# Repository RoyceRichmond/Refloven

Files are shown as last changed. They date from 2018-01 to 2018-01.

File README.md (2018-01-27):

# Refloven

this projects aims to be a low cost and customisable reflow oven board, i inspired this in the job made by @rocketscream reflow oven shield with some additional hardware so it can have more I/O pins avaliable and also usb so there's need of external programmer.

currently working to fix some problems, v2 is actually really stable and works fine. have fun and as a side note, use the v1 to make the v2 got it ? (like a 3d printer )

v1 is the easies one to build, all by hand and some extra wire.

v2 is a little more complicated to, but if you sucessfully assembled v1 and tested it you have everything on your side. it works either with 328p or 328pb only difference is how to program it and the mapping of the i/o

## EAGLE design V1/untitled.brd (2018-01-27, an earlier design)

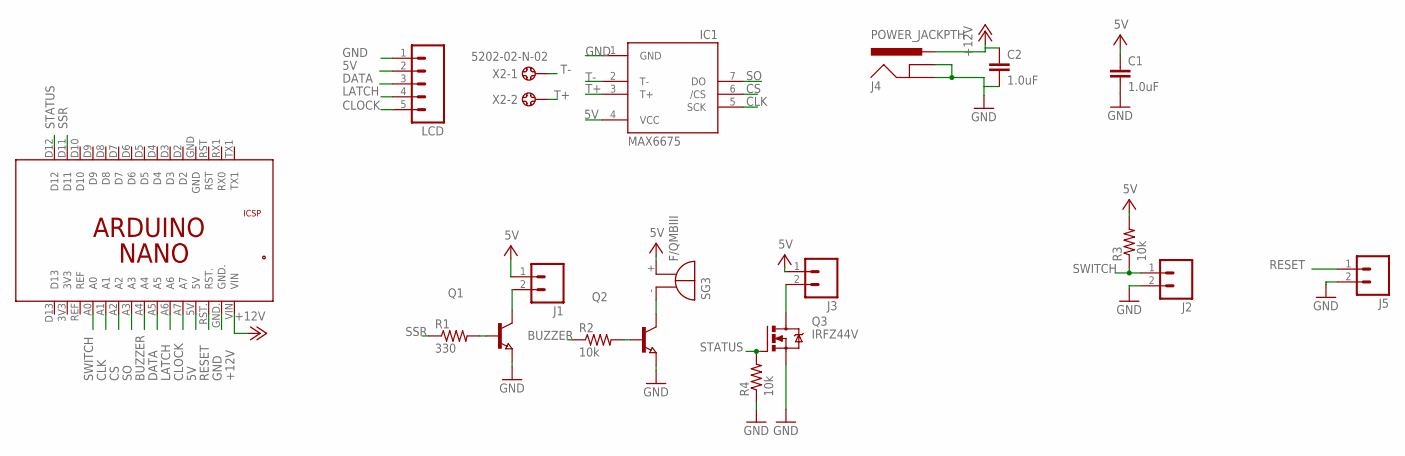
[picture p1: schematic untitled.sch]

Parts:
C1, C2: 1.0uF; 1206-CAP
IC1: MAX6675; SO08
J1, J2, J3, J5: M02PTH; 1X02
J4: POWER_JACKPTH; POWER_JACK_PTH
LCD: M05PTH; 1X05
PCB2: ARDUINO_NANO_RHEYD; ARDUINO_NANO
Q1, Q2: NPN-TRANSISTOR_SOT23; SOT23
Q3: IRFZ44V; TO220BH
R1: 330; R1206
R2, R3, R4: 10k; R1206
SG3: F/QMBIII
X2: 5202-02-N-02

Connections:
5V: C1.1, IC1.4 (VCC), J1.1, J3.1, LCD.2, PCB2.5V, R3.2, SG3.+ (-)
+12V: C2.1, J4.PWR, PCB2.VIN
BUZZER: PCB2.A4, R2.1
CLK: IC1.5 (SCK), PCB2.A1
CLOCK: LCD.5, PCB2.A7
CS: IC1.6 (/CS), PCB2.A2
DATA: LCD.3, PCB2.A5
GND: C1.2, C2.2, IC1.1 (GND), J2.2, J4.GND, J4.GNDBREAK, J5.2, LCD.1, PCB2.GND., Q1.2 (E), Q2.2 (E), Q3.S, R4.1
LATCH: LCD.4, PCB2.A6
unnamed: Q1.1 (B), R1.2
unnamed: Q2.1 (B), R2.2
unnamed: Q2.3 (C), SG3.- (+)
unnamed: J1.2, Q1.3 (C)
unnamed: J3.2, Q3.D
RESET: J5.1, PCB2.RST.
SO: IC1.7 (DO), PCB2.A3
SSR: PCB2.D11, R1.1
STATUS: PCB2.D12, Q3.G, R4.2
SWITCH: J2.1, PCB2.A0, R3.1
T+: IC1.3 (T+), X2.2
T-: IC1.2 (T-), X2.1

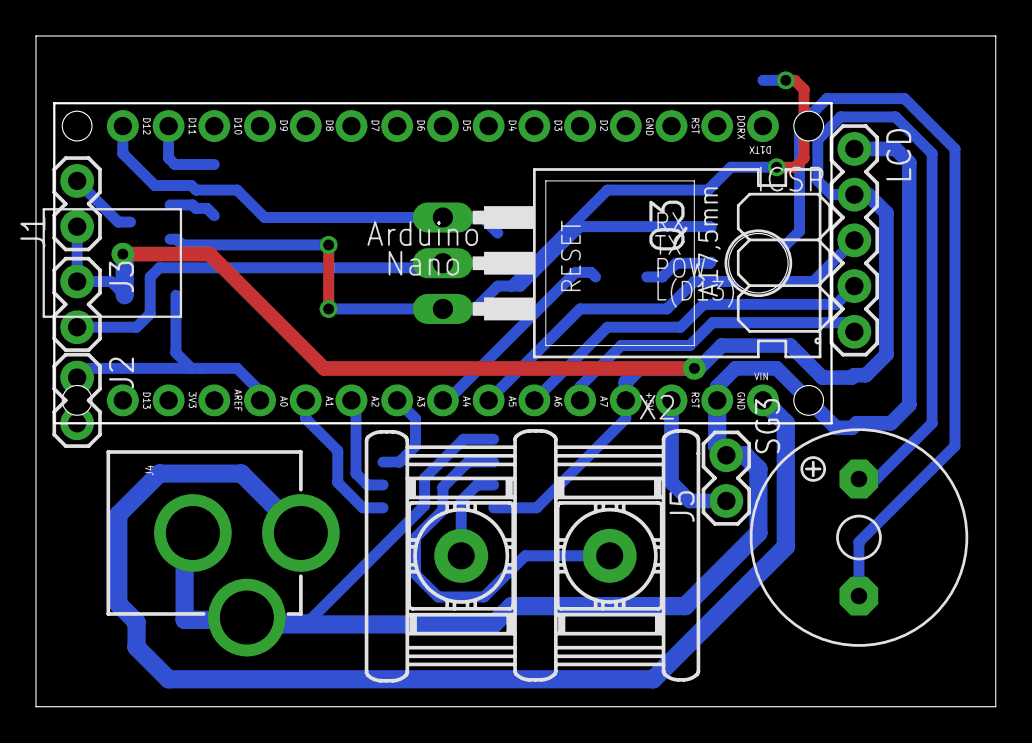
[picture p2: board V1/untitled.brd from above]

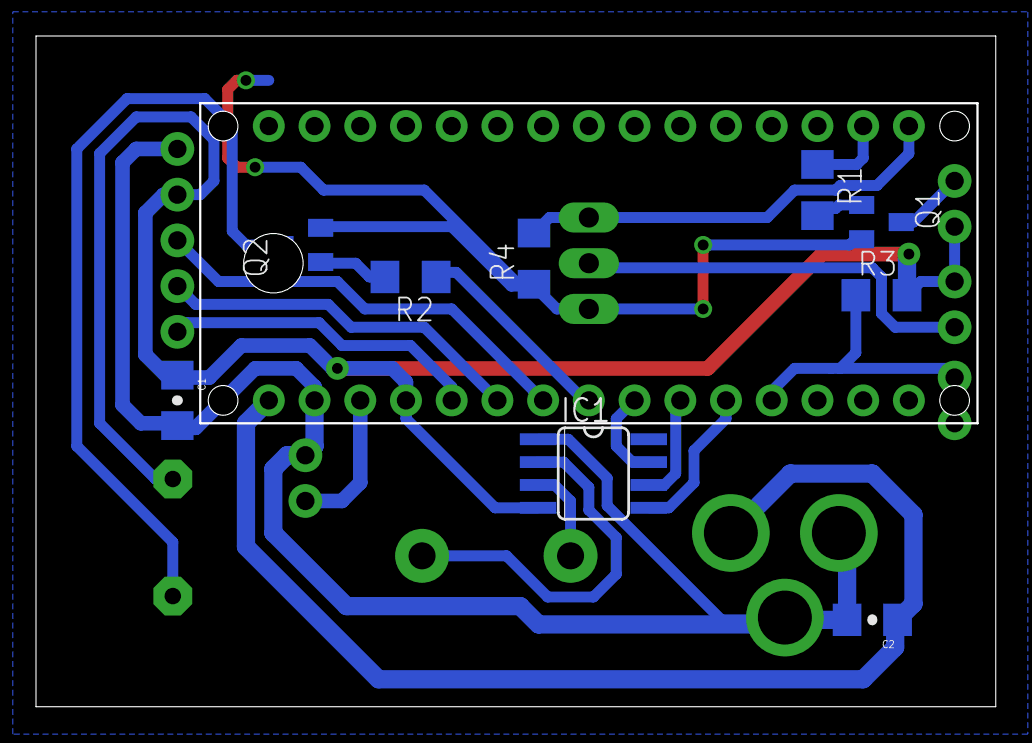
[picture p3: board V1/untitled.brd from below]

Board: 2 copper layers, 53.3 x 37.3 mm, 19 parts (9 on the bottom side), 21 nets.

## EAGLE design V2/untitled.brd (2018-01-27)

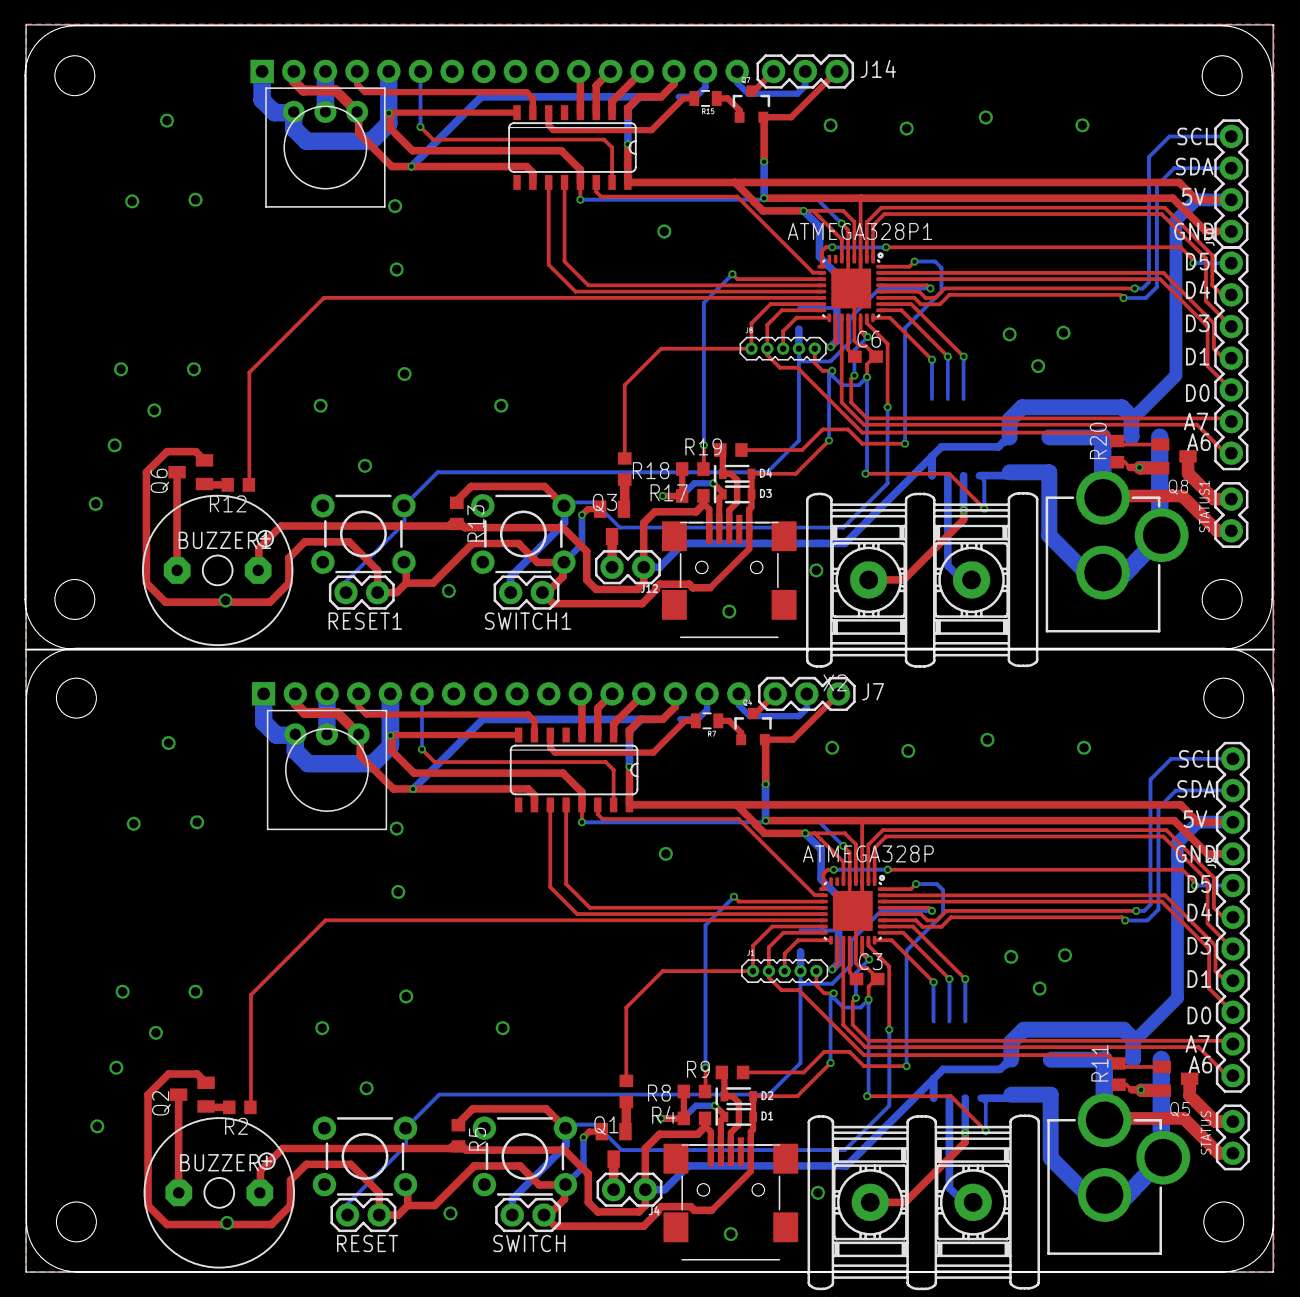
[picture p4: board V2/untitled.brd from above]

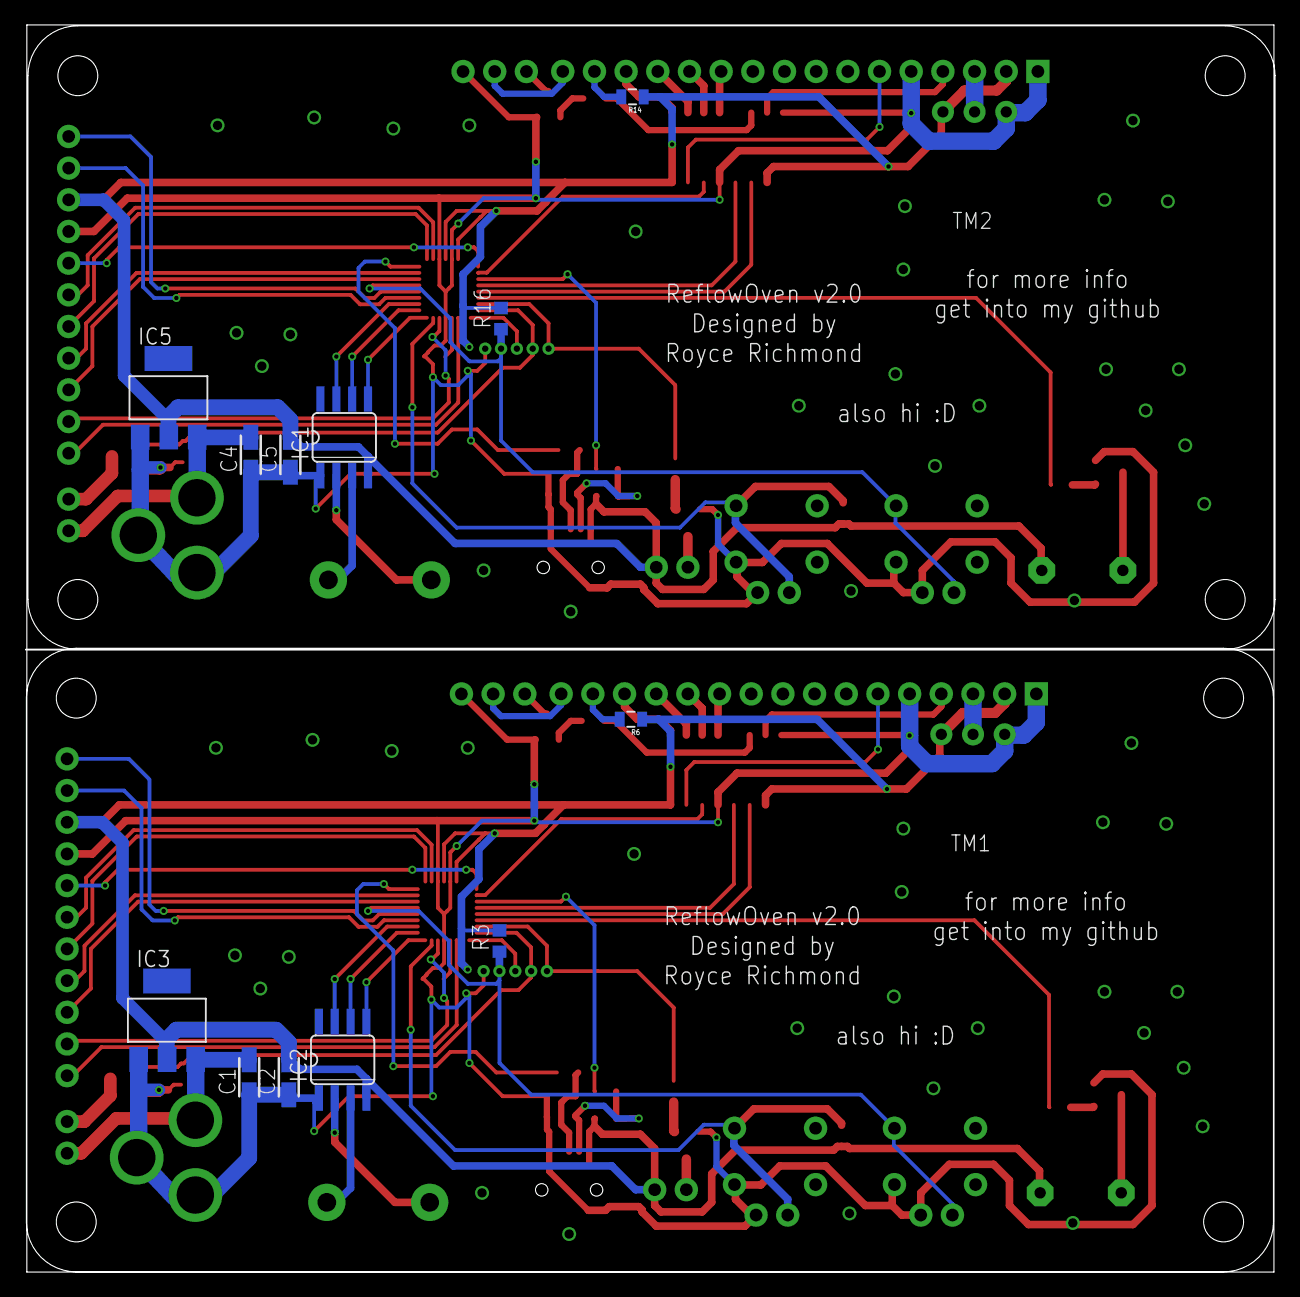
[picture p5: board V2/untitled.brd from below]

Board: 2 copper layers, 100.0 x 100.0 mm, 80 parts (12 on the bottom side), 95 nets.

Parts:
ATMEGA328P, ATMEGA328P1: MLF32-PAD
BUZZER, BUZZER1: F/QMBIII
C1, C2, C4, C5: 10uF; CT3216
C3, C6: C0603
CN1, CN2: USB-MINIB
D1, D2, D3, D4: 3.6V; SOD-323
IC1, IC2: MAX6675; SO08
IC3, IC5: REG1117; SOT223
IC4, IC6: 74LS595D; SO16
J1, J8: 1X05-1.27MM
J2, J10: 1X04
J3, J11: POWER_JACK; POWER_JACK_PTH
J4, J5, J6, J12, J13, J15: 1X02
J7, J14: 1X03
J9, J16: 1X07
PCB1, PCB2: PCB_DP_RECTANGLE-50X100; DP10050_V1
Q1, Q2, Q3, Q5, Q6, Q8: SOT23
Q4, Q7: MMBT2222A; SOT23-3
R1, R2, R10, R12: 330; R0603
R3, R5, R11, R13, R16, R20: 10k; R0603
R4, R17: 1.5K; R0603
R6, R14: 330; 0805
R7, R15: 1K; 0805
R8, R9, R18, R19: 68; R0603
RESET, RESET1: MOMENTARY-SWITCH-SPST-PTH-6.0MM; TACTILE_SWITCH_PTH_6.0MM
STATUS, STATUS1: 1X02
SWITCH, SWITCH1: MOMENTARY-SWITCH-SPST-PTH-6.0MM; TACTILE_SWITCH_PTH_6.0MM
TM1, TM2: TRIM-3386
U1, U3: LCD-16X2NOHOLES; LCD-16X2_NOHOLES
X1, X2: 5202-02-N-02

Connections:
+5V: ATMEGA328P.4, ATMEGA328P.6, ATMEGA328P.18, BUZZER.+, C2.+, CN1.VBUS, IC2.4, IC3.2, IC4.10, IC4.16, J2.2, J4.1, R3.2, R4.2, R5.2, R6.1, TM1.1, U3.2
+5V1: ATMEGA328P1.4, ATMEGA328P1.6, ATMEGA328P1.18, BUZZER1.+, C5.+, CN2.VBUS, IC1.4, IC5.2, IC6.10, IC6.16, J10.2, J12.1, R13.2, R14.1, R16.2, R17.2, TM2.1, U1.2
+12V: C1.+, IC3.3, J3.PWR, STATUS.1
+12V1: C4.+, IC5.3, J11.PWR, STATUS1.1
A1: ATMEGA328P1.19, J16.1
A2: ATMEGA328P1.22, J16.2
A6: ATMEGA328P.19, J9.1
A7: ATMEGA328P.22, J9.2
BUZZER: ATMEGA328P.14, R2.1
BUZZER1: ATMEGA328P1.14, R12.1
CLK: ATMEGA328P.24, IC2.5
CLK1: ATMEGA328P1.24, IC1.5
CLOCK: ATMEGA328P.13, IC4.11
CLOCK1: ATMEGA328P1.13, IC6.11
CS: ATMEGA328P.25, IC2.6
CS1: ATMEGA328P1.25, IC1.6
D1: ATMEGA328P1.17, J8.3
D2: ATMEGA328P.32, R9.1
D3: ATMEGA328P.1, J9.5
D4: ATMEGA328P.2, J9.6
D5: ATMEGA328P.9, J9.7
D6: ATMEGA328P1.11, R18.1
D7: ATMEGA328P.11, R8.1
D8: ATMEGA328P1.9, J16.7
D9: ATMEGA328P1.2, J16.6
D10: ATMEGA328P1.1, J16.5
D11: ATMEGA328P1.32, R19.1
D13: ATMEGA328P.17, J1.3
DATA: ATMEGA328P.10, IC4.14
DATA1: ATMEGA328P1.10, IC6.14
GND: ATMEGA328P.3, ATMEGA328P.5, ATMEGA328P.21, ATMEGA328P.PAD, ATMEGA328P1.3, ATMEGA328P1.5, ATMEGA328P1.21, ATMEGA328P1.PAD, C1.-, C2.-, C3.2, C4.-, C5.-, C6.2, CN1.GND, CN2.GND, D1.A, D2.A, D3.A, D4.A, IC1.1, IC2.1, IC3.1, IC4.8, IC4.13, IC5.1, IC6.8, IC6.13, J1.5, J2.1, J3.GND, J3.GNDBREAK, J5.2, J6.2, J7.1, J8.5, J10.1, J11.GND, J11.GNDBREAK, J13.2, J14.1, J15.2, Q1.2, Q2.2, Q3.2, Q4.2, Q5.2, Q6.2, Q7.2, Q8.2, R11.1, R20.1, RESET.1, RESET1.1, SWITCH.1, SWITCH1.1, TM1.3, TM2.3, U1.1, U1.5, U3.1, U3.5
LATCH: ATMEGA328P.12, IC4.12
LATCH1: ATMEGA328P1.12, IC6.12
unnamed: BUZZER.-, Q2.3
unnamed: IC2.2, X1.1
unnamed: IC2.3, X1.2
unnamed: Q1.1, R1.2
unnamed: Q2.1, R2.2
unnamed: ATMEGA328P.20, C3.1
unnamed: J4.2, Q1.3
unnamed: R6.2, U3.15
unnamed: TM1.2, U3.3
unnamed: IC4.7, U3.4
unnamed: IC4.15, U3.6
unnamed: IC4.4, U3.11
unnamed: IC4.3, U3.12
unnamed: IC4.2, U3.13
unnamed: IC4.1, U3.14
unnamed: J7.2, U3.16
unnamed: J7.3, Q4.3
unnamed: Q4.1, R7.1
unnamed: IC4.6, R7.2
unnamed: CN1.D-, D1.C, R4.1, R8.2
unnamed: CN1.D+, D2.C, R9.2
unnamed: BUZZER1.-, Q6.3
unnamed: IC1.2, X2.1
unnamed: Q5.3, STATUS.2
unnamed: IC1.3, X2.2
unnamed: Q3.1, R10.2
unnamed: Q6.1, R12.2
unnamed: J12.2, Q3.3
unnamed: R14.2, U1.15
unnamed: TM2.2, U1.3
unnamed: IC6.7, U1.4
unnamed: IC6.15, U1.6
unnamed: IC6.4, U1.11
unnamed: IC6.3, U1.12
unnamed: IC6.2, U1.13
unnamed: IC6.1, U1.14
unnamed: J14.2, U1.16
unnamed: J14.3, Q7.3
unnamed: Q7.1, R15.1
unnamed: IC6.6, R15.2
unnamed: ATMEGA328P1.20, C6.1
unnamed: CN2.D-, D3.C, R17.1, R18.2
unnamed: CN2.D+, D4.C, R19.2
unnamed: Q8.3, STATUS1.2
RESET: ATMEGA328P.29, J1.4, J5.1, R3.1, RESET.3
RESET1: ATMEGA328P1.29, J8.4, J15.1, R16.1, RESET1.3
RXD: ATMEGA328P.30, J9.3
RXD1: ATMEGA328P1.30, J16.3
SCL: ATMEGA328P.28, J2.4
SCL1: ATMEGA328P1.28, J10.4
SDA: ATMEGA328P.27, J2.3
SDA1: ATMEGA328P1.27, J10.3
SO: ATMEGA328P.26, IC2.7
SO1: ATMEGA328P1.26, IC1.7
SSR: ATMEGA328P.15, J1.1, R1.1
SSR1: ATMEGA328P1.15, J8.1, R10.1
STATUS: ATMEGA328P.16, J1.2, Q5.1, R11.2
STATUS1: ATMEGA328P1.16, J8.2, Q8.1, R20.2
SWITCH: ATMEGA328P.23, J6.1, R5.1, SWITCH.3
SWITCH1: ATMEGA328P1.23, J13.1, R13.1, SWITCH1.3
TXD: ATMEGA328P.31, J9.4
TXD1: ATMEGA328P1.31, J16.4

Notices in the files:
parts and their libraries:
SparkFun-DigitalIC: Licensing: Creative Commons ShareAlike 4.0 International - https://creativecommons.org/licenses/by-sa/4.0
